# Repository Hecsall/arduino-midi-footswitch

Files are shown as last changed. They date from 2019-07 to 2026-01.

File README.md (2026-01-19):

# Arduino MIDI Footswitch

A USB MIDI footswitch built with Arduino, configurable via a Web UI

> **Disclaimer:**  
> Just a heads-up: I’m not a C developer.  
> This project came together thanks to lots of online resources, documentation, trial and error, and modern tools like GitHub Copilot.  
> I don’t plan to actively maintain or support this project, but it might still be useful as a small reference or starting point for others.  
> Hopefully it helps someone out 😄

---

## Features

### Multiple Layers

This MIDI footswitch changes its behavior based on the position of a rear switch.  
With a 3-way switch, you get **3 different “layers”** of MIDI commands you can send.

### Modularity

The firmware is designed to let you easily add or remove **Buttons**, **LEDs**, and **Potentiometers** (the latter not fully tested yet) with minimal configuration.

At the top of the `firmware.ino` file, you’ll find the  
`--- USER HARDWARE DEFINITION --` section:

```c
// Layers (usually 3 with a 3-way switch)
const int NUM_LAYERS = 3;

// Format:
// {hardware_type, arduino_pin, numerical_id}
HardwareComponent hardware[] = {
  // Buttons
  { COMP_BUTTON, 5, 0 },
  { COMP_BUTTON, 6, 1 },
  { COMP_BUTTON, 7, 2 },
  { COMP_BUTTON, 8, 3 },
  { COMP_BUTTON, 9, 4 },

  // LEDs (not configurable, just match the same button IDs)
  { COMP_LED, 10, 0 },
  { COMP_LED, 16, 1 },
  { COMP_LED, 14, 2 },
  { COMP_LED, 15, 3 },
  { COMP_LED, 18, 4 },

  // Potentiometers
  // { COMP_POT, A1, 5 }
};
```

Also, a `MAX_CONTROLS` variable statically sets the maximum number of controls you can have to **20**.\
This is used to generate a fixed configuration object inside Arduino's memory to avoid filling too much memory and to avoid other issues.

### Configurator App

Using the web app included in this repo (under `app/`), you can connect to the footswitch via **Web Serial** and customize each control.

When connected, the configurator reads your pedal’s hardware definition and automatically adjusts the UI to match it.

You can:

- Load the configuration stored on the Arduino
- Save a configuration to the Arduino
- Import/Export your configuration as JSON
- Change which **Note** or **CC** MIDI message is sent
- Set **ON/OFF** values for buttons (0-127)
- Choose between **Momentary** or **Toggle** button behavior

All settings are stored in the Arduino’s **EEPROM**, so they persist even after disconnecting power.

> [!NOTE]  
> Live demo: [https://hecsall.github.io/arduino-midi-footswitch/](https://hecsall.github.io/arduino-midi-footswitch/)

Web Configurator

---

## Running the Web Configurator

See the `README.md` inside the `app/` folder.

---

## How to Build

1. [Materials](#materials)
2. [Hardware setup](#hardware-setup)
3. [Software setup](#software-setup)
4. [Rename the device](#rename-the-device)
5. [Usage](#usage)

---

## Materials

- SparkFun Pro Micro 16MHz (or another similar Arduino)

    SparkFun Pro Micro

- [Push buttons](https://www.amazon.com/Etopars-Guitar-Effects-Momentary-Button/dp/B076V2QYSJ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)
  
    Push Button

- [Switch ON-OFF-ON](https://www.amazon.com/SALECOM-Position-Guitar-Toggle-Switches/dp/B01JDUBBJQ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)

    Switch ON-OFF-ON

- Something to use as a Case, I used an [Aluminium Box](https://www.amazon.com/s?k=aluminium+stompbox&ref=nb_sb_noss)

    Aluminium Box

- [LEDs](https://www.amazon.com/Lights-Emitting-Assortment-Arduino-300-Pack/dp/B00UWBJM0Q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) - *optional*

- [10 KΩ 1/2W resistors](https://www.amazon.com/uxcell-10KOhm-Resistors-Tolerances-100Pcs/dp/B07LGK9153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) - *optional*, depending on which LEDs you use

    10 KΩ resistor

- [USB Panel Mount](https://www.amazon.com/s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) - *optional but highly suggested*, since the Pro Micro USB can break pretty easily.

    USB Panel Mount

---

## Hardware Setup

This build uses:
- 5 push buttons  
- 5 LEDs (one per button, each with a 10 kΩ resistor)  
- 1 rear ON-OFF-ON switch for selecting layers  

If you use different pins or a different board, remember to update the pin numbers in the firmware accordingly.

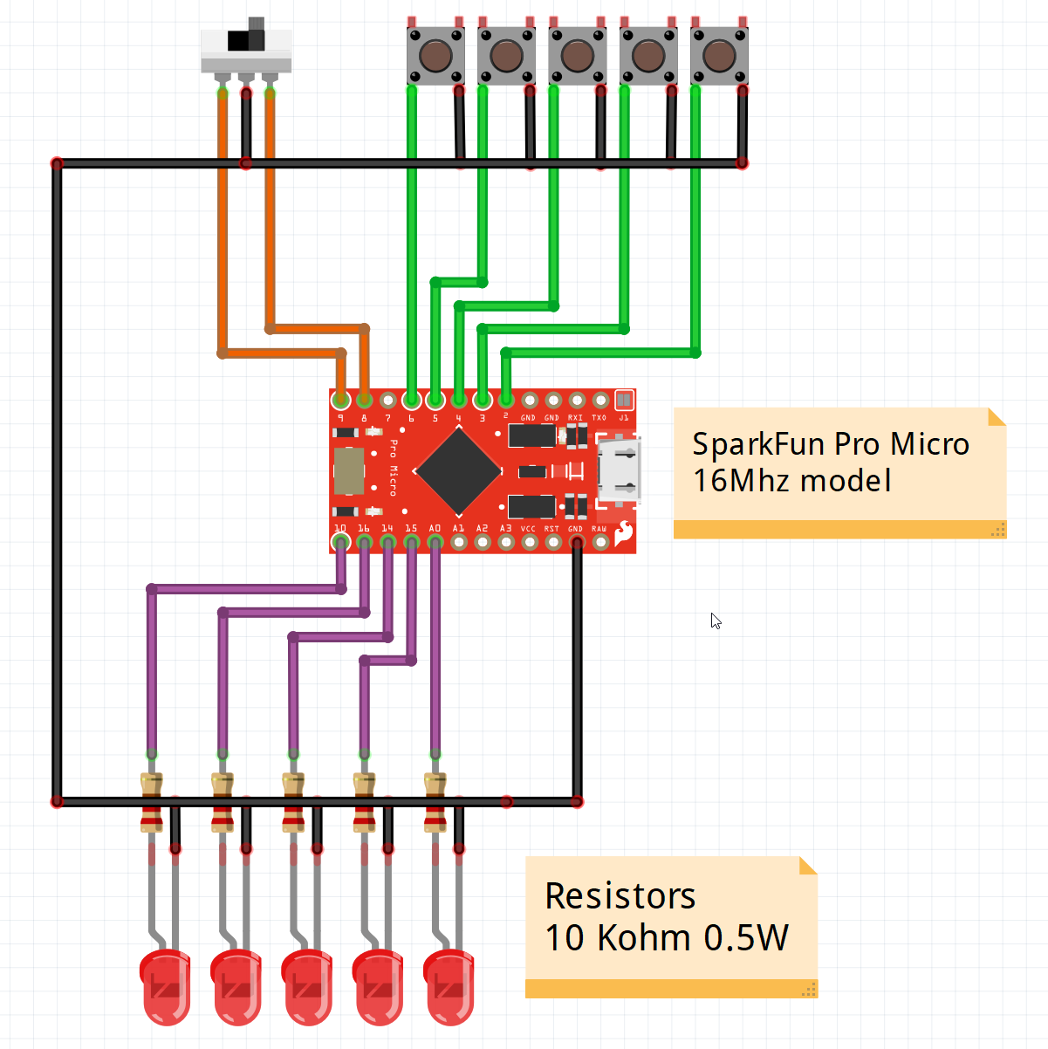
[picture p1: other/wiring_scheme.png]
Arduino MIDI Footswitch Wiring


Arduino MIDI Footswitch Wiring

First I soldered everything in place, I used a small breadboard and some male plugs just to make everything cleaner and detachable, but you can solder directly on the SparkFun if you want to.

Soldered SparkFun

Then I put everything in an Aluminium Box with some holes for Buttons, LEDs, the switch, and the USB port.

Aluminium Box

⚠️ If your enclosure is metal, insulate the bottom to avoid short circuits.

Aluminium Box

Connect some wires, put the SparkFun into the enclosure, and you are done with the hardware part!

Wires
Wires
Wires
Aluminium Box with buttons

---

## Software Setup

Assuming you already have the **Arduino IDE** installed:

1. Open **Sketch → Include Library → Manage Libraries**
2. _If you are using a SparkFun Pro Micro_:
  - Install the board in your Arduino IDE following this guide the "Installing the Arduino Addon" section:
[https://learn.sparkfun.com/tutorials/pro-micro--fio-v3-hookup-guide/installing-windows#windows_boardaddon](https://learn.sparkfun.com/tutorials/pro-micro--fio-v3-hookup-guide/installing-windows#windows_boardaddon)
3. Install **MIDIUSB** by Arduino
4. Open `firmware/firmware.ino` and customize pin numbers if changed
5. Select the correct board and CPU frequency
6. Upload the firmware

If everything is correct, you should see incoming MIDI messages when pressing buttons, using an app like [MIDI Tools](https://mountainutilities.eu/miditools) or directly using your DAW.

Arduino Footswitch

---

## Rename the Device (Optional)

By default, the board will appear using its stock name (e.g. *SparkFun Pro Micro*).

To rename it, follow this guide by **nebhead**:  
https://gist.github.com/nebhead/c92da8f1a8b476f7c36c032a0ac2592a

An example board definition is included in the `other/` folder.

---

## Useful Links

- SparkFun Pro Micro setup:  
  [https://learn.sparkfun.com/tutorials/pro-micro--fio-v3-hookup-guide/installing-windows#windows_boardaddon](https://learn.sparkfun.com/tutorials/pro-micro--fio-v3-hookup-guide/installing-windows#windows_boardaddon)
- MIDIUSB library:  
  [https://www.arduino.cc/en/Reference/MIDIUSB](https://www.arduino.cc/en/Reference/MIDIUSB)
- MIDI CC table:  
  [https://www.midi.org/specifications-old/item/table-3-control-change-messages-data-bytes-2](https://www.midi.org/specifications-old/item/table-3-control-change-messages-data-bytes-2)

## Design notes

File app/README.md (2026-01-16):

# MIDI Pedal Web Configurator

React web application that communicates directly with the MIDI Footswitch using the **Web Serial API**.

> [!NOTE]
> See it live at [https://hecsall.github.io/arduino-midi-footswitch/](https://hecsall.github.io/arduino-midi-footswitch/)

Web Configurator

## Usage

1. Connect the footswitch via USB
2. Click **Connect Device** in the browser
3. Select the Arduino/Serial device from the browser popup
4. Use **Load from pedal** to read settings and **Save** to write them

## Development

### Prerequisites

- Node.js <=18
- A Web Serial compatible browser (Chrome, Edge)

### How to Run

1. **Install Dependencies**

   ```bash
   cd webserial_app
   npm install
   ```

2. **Start Dev Server**

   ```bash
   npm run dev
   ```

   Open `http://localhost:5173`

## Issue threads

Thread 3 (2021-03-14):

Can you add a license to the Raspberry PI midi Repo ?

Mylab6, 2021-03-14:
Hi,

I've been able to make fantastic progress building upon your amazing work. Could you add a license to it( MIT would be awesome !)

Hecsall, 2021-11-14:
Hi Mylab6!
Thank you for taking the time to file this issue, I'm sorry for the (huge) delay, I didn't notice this issue before, I completely lost the notification.
As per your request, I added the MIT LICENSE file (I'm not really used to adding license files, my bad).

Hope your project is going well!

Closed 2021-11-14.

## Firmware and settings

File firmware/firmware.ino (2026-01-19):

#include "MIDIUSB.h"
#include <EEPROM.h>

/*
  MIDI Footswitch Firmware
*/

enum ComponentType {
  COMP_BUTTON,
  COMP_LED,
  COMP_POT
};

struct HardwareComponent {
  ComponentType type;
  int pin;
  int logicalId; // Maps to Config index (0..NUM_CONTROLS-1)
};

// --- USER HARDWARE DEFINITION --
const int NUM_LAYERS = 3; // L, Center, R

HardwareComponent hardware[] = {
  // Buttons
  { COMP_BUTTON, 5, 0 },
  { COMP_BUTTON, 6, 1 },
  { COMP_BUTTON, 7, 2 },
  { COMP_BUTTON, 8, 3 },
  { COMP_BUTTON, 9, 4 },
  
  // LEDs (not configurable, just match the same button ids)
  { COMP_LED, 10, 0 },
  { COMP_LED, 16, 1 },
  { COMP_LED, 14, 2 },
  { COMP_LED, 15, 3 },
  { COMP_LED, 18, 4 },

  // Potentiometers
  // { COMP_POT, A1, 5 }
};
// --- End USER HARDWARE DEFINITION --

// MAX_CONTROLS defines the storage limit and array sizes. 
// Should be large enough to accommodate mostly any setup
const int MAX_CONTROLS = 20;
// numControls will be calculated automatically in setup() based on hardware definitions.
int numControls = 0; 

const int HW_COUNT = sizeof(hardware) / sizeof(hardware[0]);

// Switch Pins (3-way toggle: ON-OFF-ON)
// Pos 1: L=GND, R=FLOAT -> Layer 0
// Pos 2: L=FLOAT, R=FLOAT -> Layer 1 (Center)
// Pos 3: L=FLOAT, R=GND -> Layer 2
const int SWITCH_PIN_L = 1;
const int SWITCH_PIN_R = 0;

// Protocol Constants
const int TYPE_NOTE = 0;
const int TYPE_CC = 1;
const int MODE_MOMENTARY = 0;
const int MODE_TOGGLE = 1;

// EEPROM Storage Address
const int EEPROM_START_ADDR = 0;

// Header signature. Change to force EEPROM reset when structure changes.
const char EEPROM_SIG[2] = {'M', 'G'};

// Struct for Control Settings
struct ControlConfig {
  uint8_t type;    // TYPE_NOTE or TYPE_CC
  uint8_t value;   // Note number or CC number
  uint8_t mode;    // MODE_MOMENTARY or MODE_TOGGLE
  uint8_t channel; // MIDI Channel (default 1)
  uint8_t minValue; // Value for OFF/Release
  uint8_t maxValue; // Value for ON/Press
};

// Storage for all layers [Layer][Control]
ControlConfig controlConfigs[NUM_LAYERS][MAX_CONTROLS];

// State tracking
bool lastButtonState[MAX_CONTROLS]; // HIGH = Released
int lastPotValue[MAX_CONTROLS]; // 0-127
bool toggleState[NUM_LAYERS][MAX_CONTROLS]; // Toggle state per layer
int activeLayer[MAX_CONTROLS]; // Tracks which layer was active when button was pressed
unsigned long lastDebounceTime[MAX_CONTROLS];
// Debounce to prevent accidental excessive button readings.
unsigned long debounceDelay = 10; 
int ppqn = 0;
unsigned long beatLedOffTime = 0;

// Forward declarations
void setDefaults();
int getCurrentLayer();
void handleSerial();
void handleMidi();
void readHardware();
void updateLEDs();
void parseCommand(String cmd);
void saveConfig();
void loadConfig();
void handlePress(int idx, int layer);
void handleRelease(int idx, int layer);
void sendNoteOn(byte channel, byte pitch, byte velocity);
void sendNoteOff(byte channel, byte pitch, byte velocity);
void sendCC(byte channel, byte control, byte value);


void setup() {
  Serial.begin(115200);

  // Auto-detect number of controls based on max logicalId in hardware array
  int maxLogicalId = -1;
  for (int i = 0; i < HW_COUNT; i++) {
    if (hardware[i].logicalId > maxLogicalId) {
      maxLogicalId = hardware[i].logicalId;
    }
  }
  numControls = maxLogicalId + 1;
  if (numControls > MAX_CONTROLS) numControls = MAX_CONTROLS; // Safety clamp

  // Init State Arrays
  for(int i=0; i<MAX_CONTROLS; i++) {
    lastButtonState[i] = HIGH;
    lastPotValue[i] = -1;
    activeLayer[i] = 1; // Default Center
    lastDebounceTime[i] = 0;
  }

  // Setup Hardware Pins
  for (int i = 0; i < HW_COUNT; i++) {
    if (hardware[i].type == COMP_BUTTON) {
      pinMode(hardware[i].pin, INPUT_PULLUP);
    } else if (hardware[i].type == COMP_LED) {
      pinMode(hardware[i].pin, OUTPUT);
      digitalWrite(hardware[i].pin, LOW);
    } 
  }

  // Setup Switch Pins
  pinMode(SWITCH_PIN_L, INPUT_PULLUP);
  pinMode(SWITCH_PIN_R, INPUT_PULLUP);

  // Init toggle states
  for (int l = 0; l < NUM_LAYERS; l++) {
    for (int b = 0; b < MAX_CONTROLS; b++) {
      toggleState[l][b] = false;
    }
  }

  // Load Config from EEPROM
  loadConfig();
}

void loop() {
  handleSerial();
  handleMidi();
  readHardware();
  updateLEDs();
}

// --- Helpers ---

int getCurrentLayer() {
  if (digitalRead(SWITCH_PIN_L) == LOW) return 0;
  if (digitalRead(SWITCH_PIN_R) == LOW) return 2;
  return 1; // Center
}

// --- MIDI Handling ---

void handleMidi() {
  midiEventPacket_t rx;
  do {
    rx = MidiUSB.read();
    if (rx.byte1 == 0xF8) {
      ppqn++;
      if (ppqn == 24) {
        beatLedOffTime = millis() + 80;
        ppqn = 0;
      }
    }
  } while (rx.header != 0);
}

// --- Serial Command Handling ---

String inputBuffer = "";

void handleSerial() {
  while (Serial.available()) {
    char c = (char)Serial.read();
    if (c == '\n') {
      parseCommand(inputBuffer);
      inputBuffer = "";
    } else {
      inputBuffer += c;
    }
  }
}

void parseCommand(String cmd) {
  cmd.trim();
  if (cmd.length() == 0) return;

  if (cmd.equals("INFO")) {
    Serial.print("SYS:LAYERS:");
    Serial.println(NUM_LAYERS);
    Serial.print("SYS:CONTROLS:");
    Serial.println(numControls);
    
    // Dump Hardware Layout
    for (int i = 0; i < numControls; i++) {
      int type = -1; 
      for (int h = 0; h < HW_COUNT; h++) {
        if (hardware[h].logicalId == i) {
          if (hardware[h].type == COMP_POT) { 
             type = 1; 
             break; // Found Pot, wins
          }
          if (hardware[h].type == COMP_BUTTON) { 
             type = 0; 
          }
        }
      }
      if (type != -1) {
        Serial.print("SYS:TYPE:");
        Serial.print(i);
        Serial.print(":");
        Serial.println(type == 1 ? "POT" : "BTN");
      }
    }
    
    Serial.println("OK: INFO");
  } else if (cmd.startsWith("SET")) {
    int firstSpace = cmd.indexOf(' ');
    int secondSpace = cmd.indexOf(' ', firstSpace + 1);
    int thirdSpace = cmd.indexOf(' ', secondSpace + 1);
    int fourthSpace = cmd.indexOf(' ', thirdSpace + 1);
    int fifthSpace = cmd.indexOf(' ', fourthSpace + 1);
    int sixthSpace = cmd.indexOf(' ', fifthSpace + 1);

    if (firstSpace > 0 && secondSpace > 0 && thirdSpace > 0 && fourthSpace > 0 && fifthSpace > 0 && sixthSpace > 0) {
      int idx = cmd.substring(firstSpace + 1, secondSpace).toInt();
      int type = cmd.substring(secondSpace + 1, thirdSpace).toInt();
      int val = cmd.substring(thirdSpace + 1, fourthSpace).toInt();
      int mode = cmd.substring(fourthSpace + 1, fifthSpace).toInt();
      int minV = cmd.substring(fifthSpace + 1, sixthSpace).toInt();
      int maxV = cmd.substring(sixthSpace + 1).toInt();

      int totalItems = MAX_CONTROLS * NUM_LAYERS;
      // We need to calculate bounds based on what the App sees (numControls * NUM_LAYERS)
      int validTotal = numControls * NUM_LAYERS;

      if (idx >= 0 && idx < validTotal) {
        int layer = idx / numControls;
        int btn = idx % numControls;
        
        controlConfigs[layer][btn].type = type;
        controlConfigs[layer][btn].value = val;
        controlConfigs[layer][btn].mode = mode;
        controlConfigs[layer][btn].minValue = minV;
        controlConfigs[layer][btn].maxValue = maxV;
        Serial.println("OK: SET " + String(idx));
      }
    }
  } else if (cmd.equals("GET")) {
    // Send all stored data (MAX_CONTROLS) so App can see everything if needed, 
    // or we can limit to numControls. Restoring based on MAX is safer for EEPROM backup.
    int totalItems = MAX_CONTROLS * NUM_LAYERS;
    for (int i = 0; i < totalItems; i++) {
      int layer = i / MAX_CONTROLS;
      int btn = i % MAX_CONTROLS;
      
      // Optimization: Only send active ones to speed up
      if (btn >= numControls) continue;

      int logicalFlatIndex = (layer * numControls) + btn;

      Serial.print("BTN:");
      Serial.print(logicalFlatIndex);
      Serial.print(":");
      Serial.print(controlConfigs[layer][btn].type);
      Serial.print(":");
      Serial.print(controlConfigs[layer][btn].value);
      Serial.print(":");
      Serial.print(controlConfigs[layer][btn].mode);
      Serial.print(":");
      Serial.print(controlConfigs[layer][btn].minValue);
      Serial.print(":");
      Serial.println(controlConfigs[layer][btn].maxValue);
    }
    Serial.println("OK: GET");
  } else if (cmd.equals("SAVE")) {
    saveConfig();
    Serial.println("OK: SAVE");
  } else if (cmd.equals("RESET")) {
    setDefaults();
    saveConfig();
    Serial.println("OK: RESET");
  } else {
    Serial.println("ERR: Unknown Command");
  }
}

// --- Logic ---

void readHardware() {
  int currentLayer = getCurrentLayer();

  for (int i = 0; i < HW_COUNT; i++) {
    int idx = hardware[i].logicalId;
    if (idx < 0 || idx >= numControls) continue;

    if (hardware[i].type == COMP_BUTTON) {
        int reading = digitalRead(hardware[i].pin);
        
        if (reading != lastButtonState[idx]) {
          lastDebounceTime[idx] = millis();
        }
        
        static int stableState[MAX_CONTROLS];
        static bool initialized = false;
        if (!initialized) {
           for(int k=0; k<MAX_CONTROLS; k++) stableState[k] = HIGH;
           initialized = true;
        }

        if ((millis() - lastDebounceTime[idx]) > debounceDelay) {
          if (reading != stableState[idx]) {
              stableState[idx] = reading;

              if (stableState[idx] == LOW) { // Pressed
                activeLayer[idx] = currentLayer;
                handlePress(idx, currentLayer);
              } else { // Released
                handleRelease(idx, activeLayer[idx]);
              }
          }
        }
        lastButtonState[idx] = reading;

    } else if (hardware[i].type == COMP_POT) {
        int raw = analogRead(hardware[i].pin);
        int midiVal = raw >> 3; // 0-1023 -> 0-127
        
        // Simple hysteresis
        if (lastPotValue[idx] == -1 || abs(midiVal - lastPotValue[idx]) > 1) { 
           lastPotValue[idx] = midiVal;
           ControlConfig cfg = controlConfigs[currentLayer][idx];
           // Usually Pots are CC.
           if (cfg.type == TYPE_CC) { 
              sendCC(cfg.channel, cfg.value, midiVal);
           } else {
              // If configured as Note, send Note On with velocity = value
               if (midiVal > 0) sendNoteOn(cfg.channel, cfg.value, midiVal);
               else sendNoteOff(cfg.channel, cfg.value, 0);
           }
        }
    }
  }
}

void handlePress(int idx, int layer) {
  ControlConfig cfg = controlConfigs[layer][idx];
  
  if (cfg.mode == MODE_MOMENTARY) {
    if (cfg.type == TYPE_NOTE) sendNoteOn(0, cfg.value, cfg.maxValue);
    else sendCC(0, cfg.value, cfg.maxValue);
    
  } else if (cfg.mode == MODE_TOGGLE) {
    toggleState[layer][idx] = !toggleState[layer][idx];
    
    if (toggleState[layer][idx]) {
       if (cfg.type == TYPE_NOTE) sendNoteOn(0, cfg.value, cfg.maxValue);
       else sendCC(0, cfg.value, cfg.maxValue);
    } else {
       if (cfg.type == TYPE_NOTE) sendNoteOff(0, cfg.value, cfg.minValue);
       else sendCC(0, cfg.value, cfg.minValue);
    }
  }
}

void handleRelease(int idx, int layer) {
  ControlConfig cfg = controlConfigs[layer][idx];
  
  if (cfg.mode == MODE_MOMENTARY) {
    if (cfg.type == TYPE_NOTE) sendNoteOff(0, cfg.value, cfg.minValue);
    else sendCC(0, cfg.value, cfg.minValue);
  }
}

void updateLEDs() {
  int layer = getCurrentLayer();
  
  for (int i = 0; i < HW_COUNT; i++) {
    if (hardware[i].type == COMP_LED) {
       int idx = hardware[i].logicalId;
       if (idx < 0 || idx >= numControls) continue;
       
       bool ledOn = false;
       ControlConfig cfg = controlConfigs[layer][idx];

       if (cfg.mode == MODE_MOMENTARY) {
           ledOn = (lastButtonState[idx] == LOW);
       } else {
           ledOn = toggleState[layer][idx];
       }

       // Override first LED (logical 0) for BPM
       if (idx == 0 && millis() < beatLedOffTime) {
           ledOn = true;
       }
       
       digitalWrite(hardware[i].pin, ledOn ? HIGH : LOW);
    }
  }
}

// --- MIDI Helpers ---

void sendNoteOn(byte channel, byte pitch, byte velocity) {
  midiEventPacket_t noteOn = {0x09, 0x90 | channel, pitch, velocity};
  MidiUSB.sendMIDI(noteOn);
  MidiUSB.flush();
}

void sendNoteOff(byte channel, byte pitch, byte velocity) {
  midiEventPacket_t noteOff = {0x08, 0x80 | channel, pitch, velocity};
  MidiUSB.sendMIDI(noteOff);
  MidiUSB.flush();
}

void sendCC(byte channel, byte control, byte value) {
  midiEventPacket_t event = {0x0B, 0xB0 | channel, control, value};
  MidiUSB.sendMIDI(event);
  MidiUSB.flush();
}

// --- EEPROM ---

void saveConfig() {
  int addr = EEPROM_START_ADDR;
  EEPROM.update(addr++, EEPROM_SIG[0]);
  EEPROM.update(addr++, EEPROM_SIG[1]);
  
  for (int l = 0; l < NUM_LAYERS; l++) {
    for (int b = 0; b < MAX_CONTROLS; b++) {
      EEPROM.update(addr++, controlConfigs[l][b].type);
      EEPROM.update(addr++, controlConfigs[l][b].value);
      EEPROM.update(addr++, controlConfigs[l][b].mode);
      EEPROM.update(addr++, controlConfigs[l][b].channel);
      EEPROM.update(addr++, controlConfigs[l][b].minValue);
      EEPROM.update(addr++, controlConfigs[l][b].maxValue);
    }
  }
}

void setDefaults() {
  for (int l = 0; l < NUM_LAYERS; l++) {
    for (int b = 0; b < MAX_CONTROLS; b++) {
      controlConfigs[l][b].type = TYPE_CC;
      int baseVal = 20 + (l * 10); 
      controlConfigs[l][b].value = baseVal + b;
      controlConfigs[l][b].mode = MODE_MOMENTARY;
      controlConfigs[l][b].channel = 0;
      controlConfigs[l][b].minValue = 0;
      controlConfigs[l][b].maxValue = 127;
    }
  }
}

void loadConfig() {
  int addr = EEPROM_START_ADDR;
  char m1 = EEPROM.read(addr++);
  char m2 = EEPROM.read(addr++);
  
  if (m1 == EEPROM_SIG[0] && m2 == EEPROM_SIG[1]) {
    for (int l = 0; l < NUM_LAYERS; l++) {
      for (int b = 0; b < MAX_CONTROLS; b++) {
        controlConfigs[l][b].type = EEPROM.read(addr++);
        controlConfigs[l][b].value = EEPROM.read(addr++);
        controlConfigs[l][b].mode = EEPROM.read(addr++);
        controlConfigs[l][b].channel = EEPROM.read(addr++);
        controlConfigs[l][b].minValue = EEPROM.read(addr++);
        controlConfigs[l][b].maxValue = EEPROM.read(addr++);
      }
    }
  } else {
    setDefaults();
  }
}

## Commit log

2019-07-27 add boards.txt and updated code
2021-12-27 moved pins
    [pedal.fzz]
2021-12-30 updated readme, changed pin numbers
2021-12-30 removed arduino.json
2022-02-13 updated readme, updated boards.txt
2026-01-15 major rework, added configurator tool via web-ui
    [firmware.ino]
2026-01-17 Add reset button
2026-01-18 change default button type from Note to CC
